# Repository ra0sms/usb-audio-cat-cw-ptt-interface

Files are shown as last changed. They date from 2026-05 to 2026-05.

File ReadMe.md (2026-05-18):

## USB AUDIO CAT PTT CW interface for any transceiver

One USB connection - two USB devices. 

USB Audio Codec and COM-port for CAT CW and PTT. Based on CH334R (usb-hub), CH340C (usb-com) and CM108B (usb audio).

More information - https://ra0sms.com/usb-audio-cat-interface/

-------------------------------------------

PCB dimension: 80*48 mm

[Gerber files](KiCad/usb_audio_cat/usb_audio_cat_gerbers.zip)

[Schematic](KiCad/usb_audio_cat/usb_audio_cat.pdf)

Recommended enclosure - 80-50-20 mm (https://aliexpress.ru/item/1005006828585850.html)

### PCB

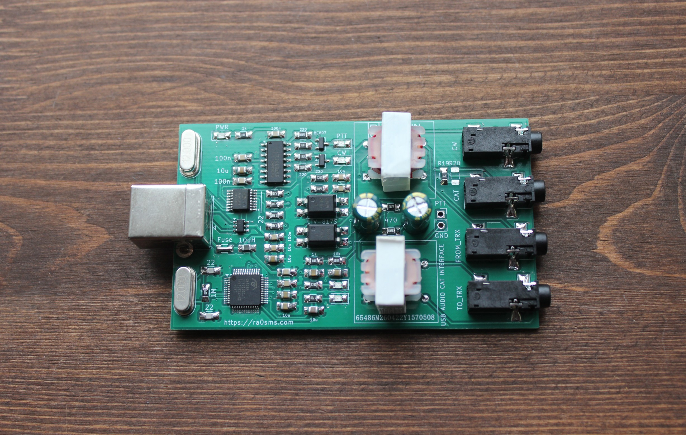
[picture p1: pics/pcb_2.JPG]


### Boxed version

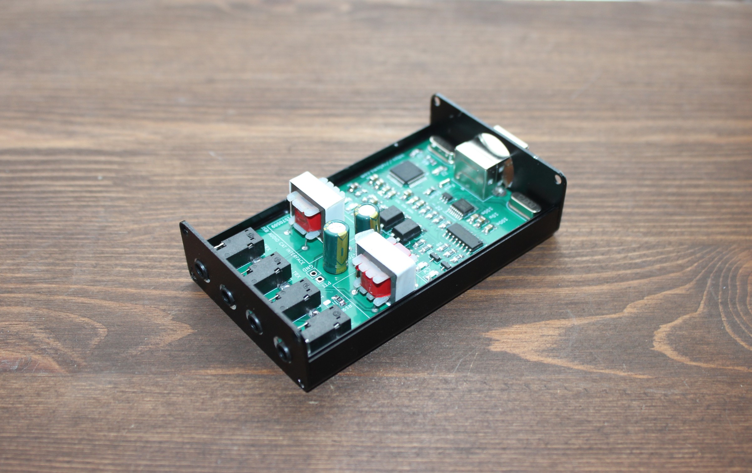
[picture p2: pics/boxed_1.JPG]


### Schematic

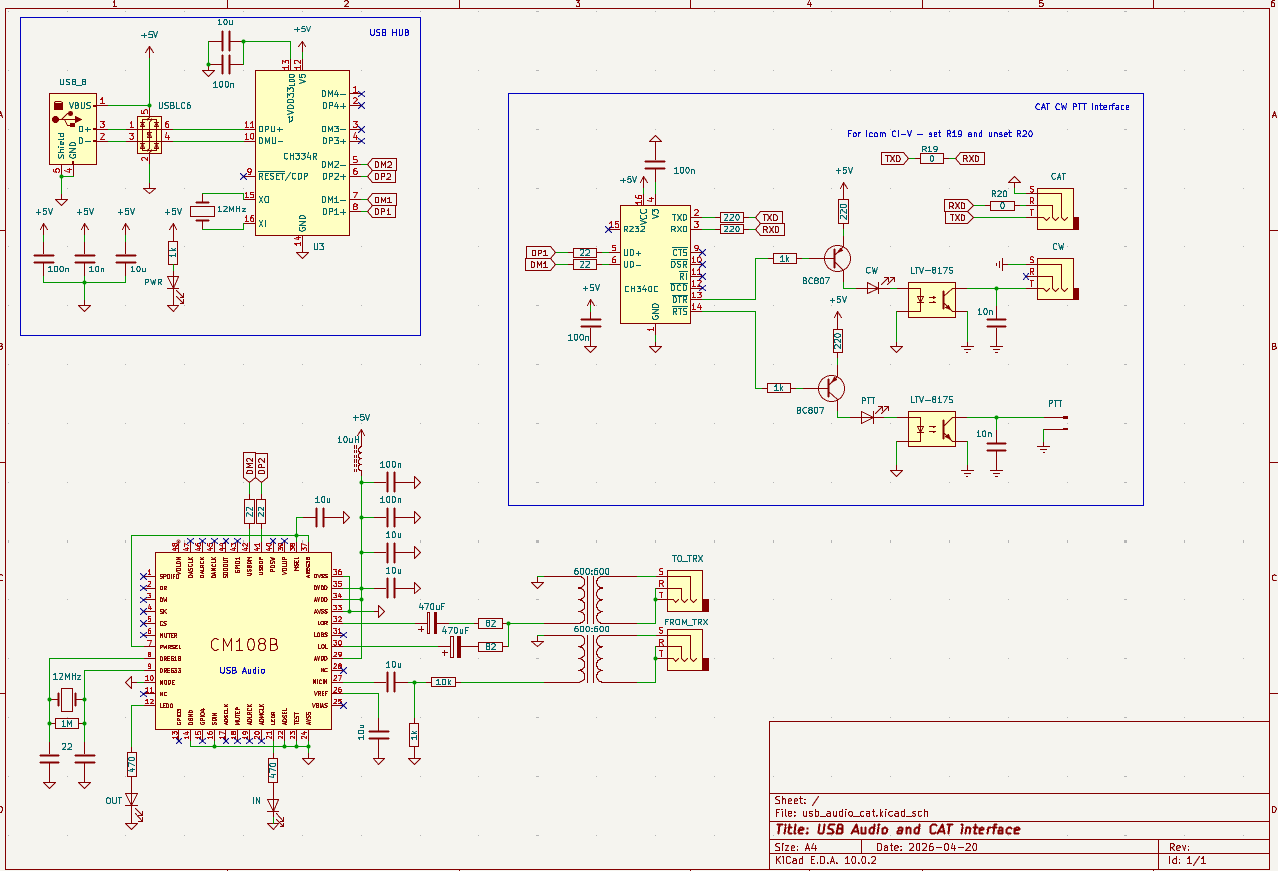
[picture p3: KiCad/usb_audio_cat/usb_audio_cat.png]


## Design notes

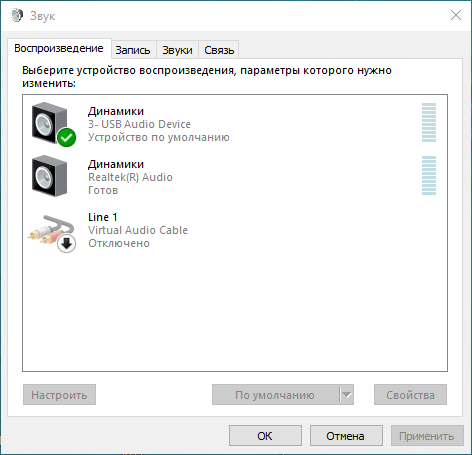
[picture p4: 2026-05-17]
pics/audio_windows_2.png

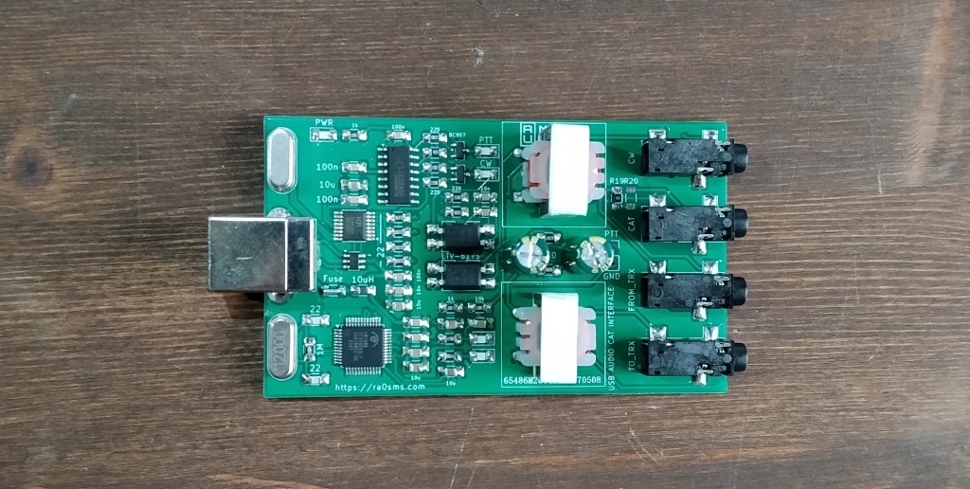
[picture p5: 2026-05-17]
pics/pcb_1.jpg

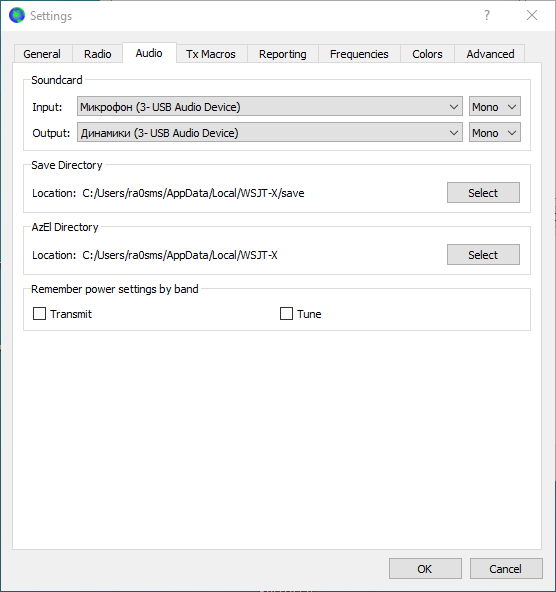
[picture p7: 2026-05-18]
pics/audio_wsjtx.png

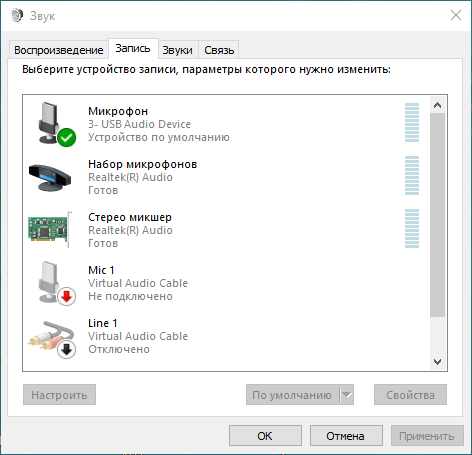
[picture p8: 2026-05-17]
pics/audio_windows_1.png

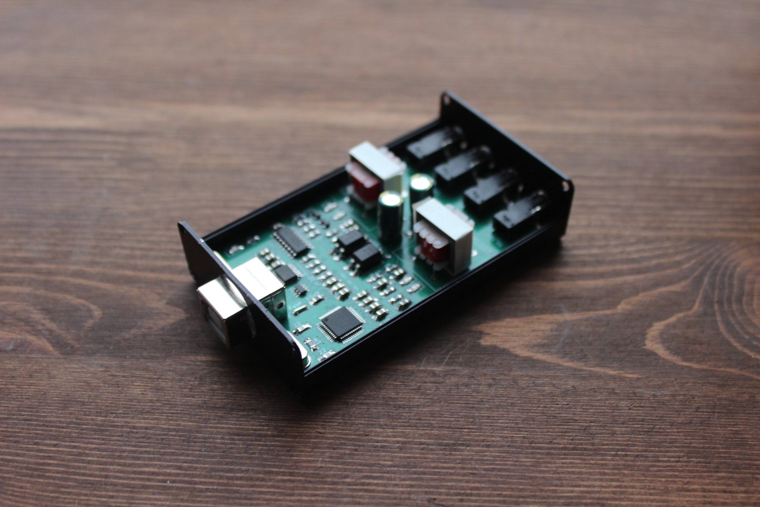
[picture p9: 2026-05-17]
pics/boxed_2.JPG

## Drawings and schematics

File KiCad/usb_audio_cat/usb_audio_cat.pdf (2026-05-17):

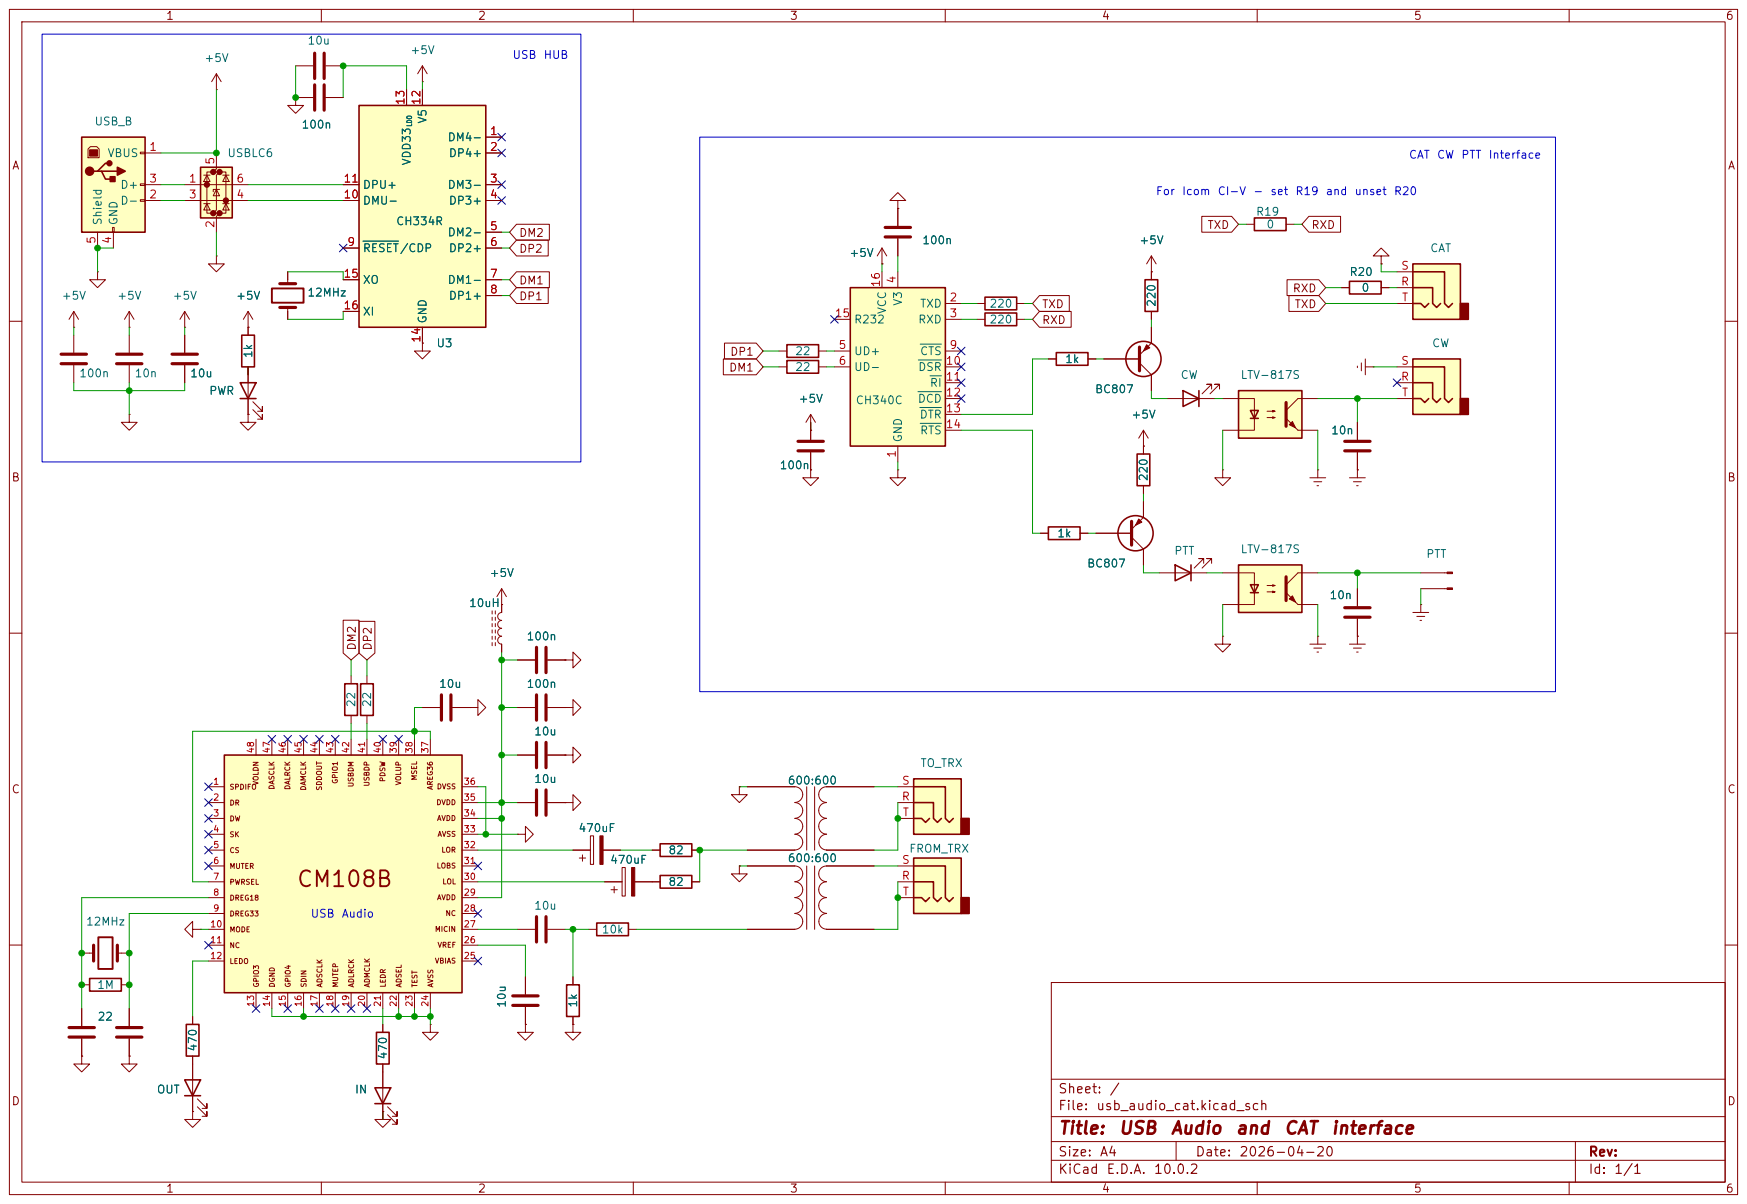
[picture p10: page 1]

For Icom CI-V - set R19 and unset R20 USB Audio

4 UD+ 5 UD- 6 CTS 9 DSR 10 RI 11 DCD 12 DTR 13 RTS 14 R232 15 VCC 16 CH340C

File: usb_audio_cat.kicad_sch
Title: USB Audio and CAT interface

Size: A4 | Rev:
KiCad E.D.A. 10.0.2 | Id: 1/1

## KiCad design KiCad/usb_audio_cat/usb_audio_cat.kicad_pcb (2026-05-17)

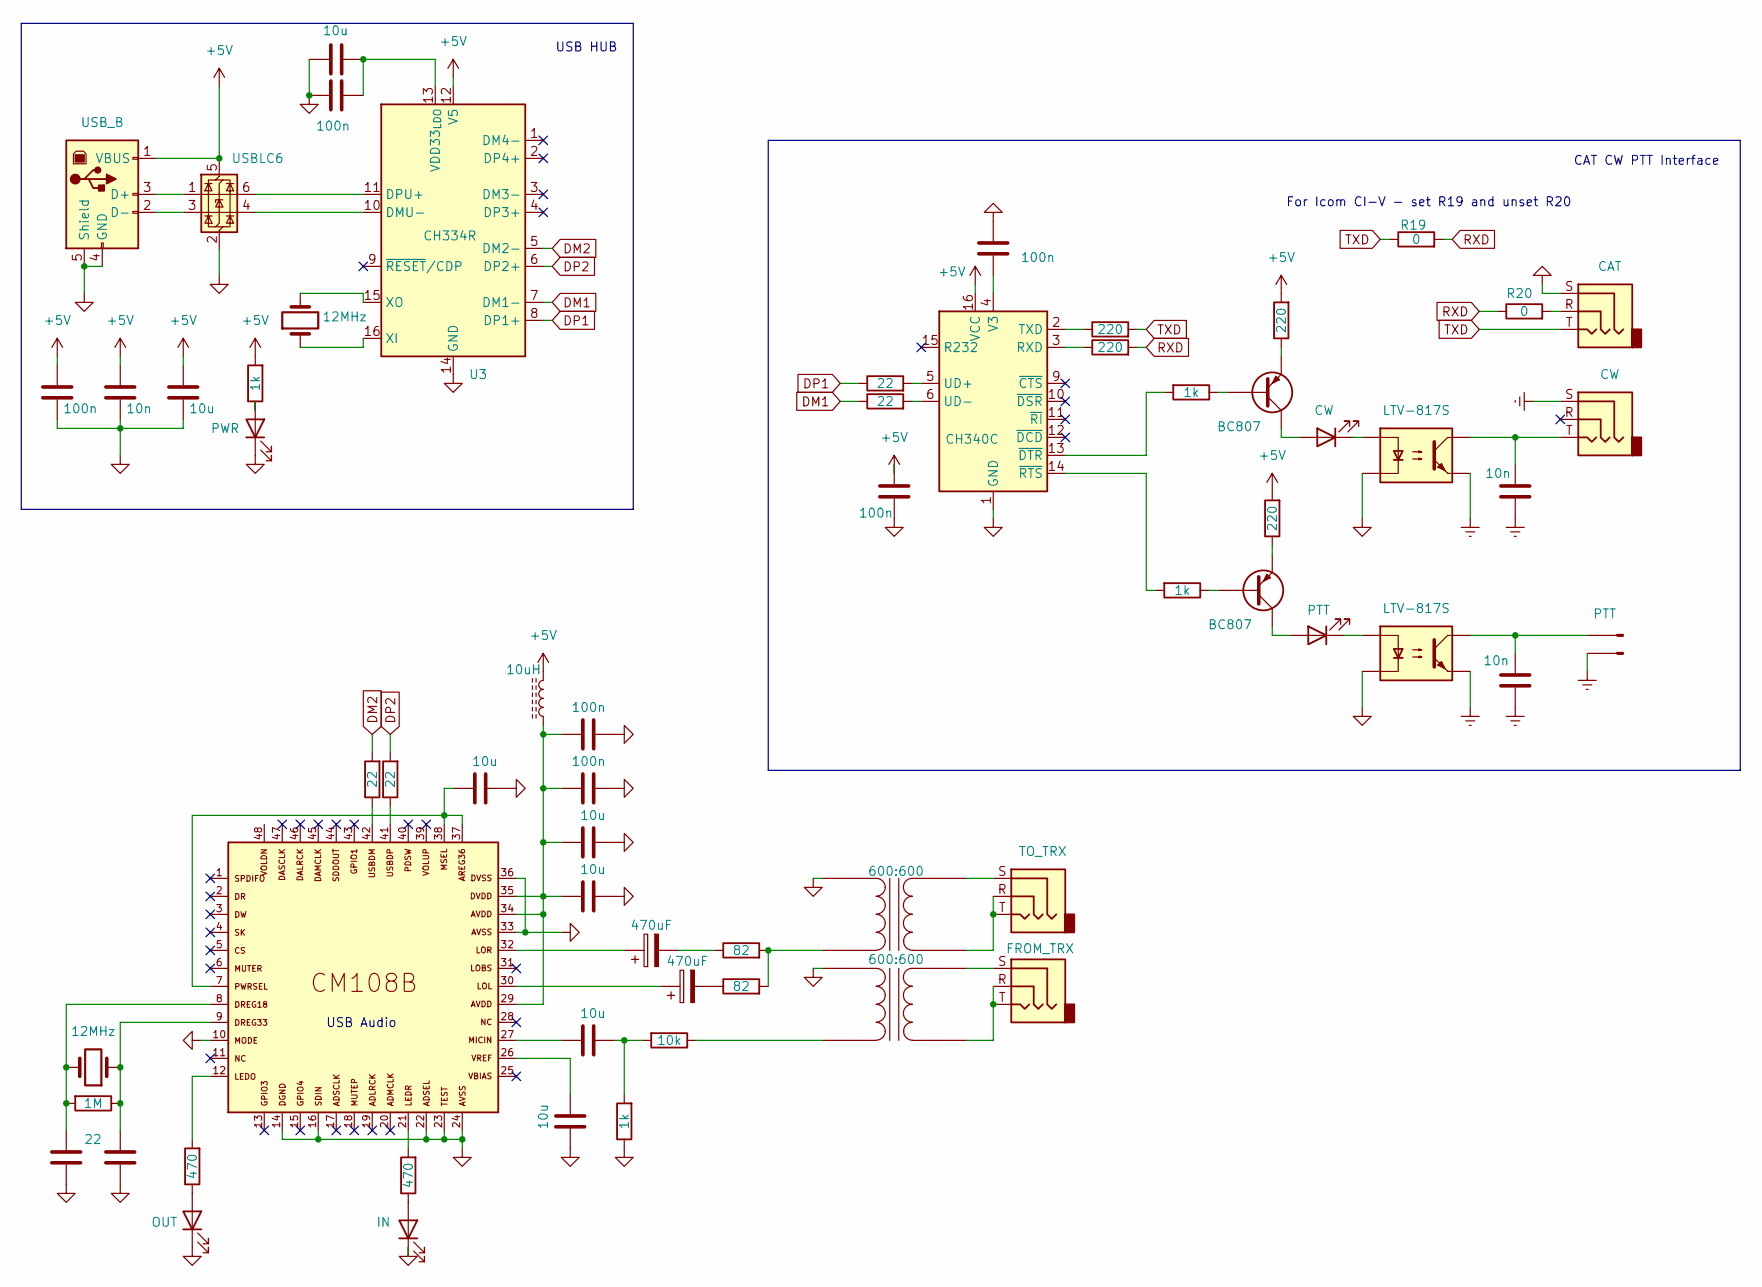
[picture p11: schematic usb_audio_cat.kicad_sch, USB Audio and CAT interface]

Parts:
C1, C3: 22; C_1206_3216Metric
C2, C7, C10, C11, C17, C18: 100n; C_1206_3216Metric
C4, C19, C20: 10n; C_1206_3216Metric
C5, C6, C8, C9, C12, C13, C14: 10u; C_1206_3216Metric
C15, C16: 470uF; CP_Radial_D5.0mm_P2.50mm
D1: PWR; LED_1206_3216Metric
D2: OUT; LED_1206_3216Metric
D3: IN; LED_1206_3216Metric
D4: PTT; LED_1206_3216Metric
D5: CW; LED_1206_3216Metric
J1: USB_B; USB_B_Lumberg_2411_02_Horizontal
J2: TO_TRX; Jack_3.5mm_CUI_SJ-3523-SMT_Horizontal
J3: FROM_TRX; Jack_3.5mm_CUI_SJ-3523-SMT_Horizontal
J4: CAT; Jack_3.5mm_CUI_SJ-3523-SMT_Horizontal
J5: CW; Jack_3.5mm_CUI_SJ-3523-SMT_Horizontal
J6: PTT; PinSocket_1x02_P2.54mm_Vertical
L1: 10uH; R_1206_3216Metric
Q1, Q2: BC807; SOT-23
R1, R7, R15, R16: 1k; R_1206_3216Metric
R2: 1M; R_1206_3216Metric
R3, R6: 470; R_1206_3216Metric
R4, R5, R11, R12: 22; R_1206_3216Metric
R8: 10k; R_1206_3216Metric
R9, R10: 82; R_1206_3216Metric
R13, R14, R17, R18: 220; R_1206_3216Metric
R19, R20: 0; R_1206_3216Metric
T1, T2: 600:600; Transformer_NF_ETAL_1-1_P1200
U1: USBLC6; SOT-23-6
U2: CM108B; LQFP-48_7x7mm_P0.5mm
U3: CH334R; QSOP-16_3.9x4.9mm_P0.635mm
U4: CH340C; SOIC-16_3.9x9.9mm_P1.27mm
U5, U6: LTV-817S; SMDIP-4_W9.53mm
Y1, Y2: 12MHz; Crystal_HC18-U_Vertical

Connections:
+5V: C2.1, C4.1, C5.1, C17.1, J1.1 (VBUS), L1.2, R1.2, R17.2, R18.2, U1.5 (VBUS), U3.12 (V5), U4.16 (VCC)
DM1: R12.1, U3.7 (DM1-)
DM2: R4.2, U3.5 (DM2-)
DP1: R11.1, U3.8 (DP1+)
DP2: R5.2, U3.6 (DP2+)
GND: C1.1, C2.2, C3.1, C4.2, C5.2, C6.1, C7.1, C8.2, C9.1, C10.2, C11.2, C12.2, C13.2, C17.2, C18.1, D1.1 (K), D2.1 (K), D3.1 (K), J1.4 (GND), J1.5 (Shield), J4.S, R7.1, T1.1 (AA), T2.1 (AA), U1.2 (GND), U2.10, U2.14, U2.16, U2.22, U2.23, U2.24, U2.33, U2.36, U3.14 (GND), U4.1 (GND), U5.2, U6.2
GNDREF: C19.2, C20.2, J5.S, J6.2, U5.3, U6.3
unnamed: C1.2, R2.2, U2.8, Y1.2
unnamed: C3.2, R2.1, U2.9, Y1.1
unnamed: C8.1, U2.7, U2.37, U2.38
unnamed: C9.2, U2.26
unnamed: C10.1, C11.1, C12.1, C13.1, L1.1, U2.29, U2.34, U2.35
unnamed: C14.1, U2.27
unnamed: C14.2, R7.2, R8.2
unnamed: C15.1, U2.32
unnamed: C15.2, R9.1
unnamed: C16.1, U2.30
unnamed: C16.2, R10.1
unnamed: C19.1, J5.T, U5.4
unnamed: D1.2 (A), R1.1
unnamed: D2.2 (A), R3.1
unnamed: D3.2 (A), R6.1
unnamed: D4.2 (A), Q1.3 (C)
unnamed: D4.1 (K), U6.1
unnamed: D5.2 (A), Q2.3 (C)
unnamed: D5.1 (K), U5.1
unnamed: J1.3 (D+), U1.1 (I/O1)
unnamed: J1.2 (D-), U1.3 (I/O2)
unnamed: J4.R, R20.2
unnamed: C20.1, J6.1, U6.4
unnamed: Q1.1 (B), R15.1
unnamed: Q1.2 (E), R17.1
unnamed: Q2.1 (B), R16.1
unnamed: Q2.2 (E), R18.1
unnamed: R3.2, U2.12
unnamed: R4.1, U2.42
unnamed: R5.1, U2.41
unnamed: R6.2, U2.21
unnamed: R9.2, R10.2, T1.3 (AB)
unnamed: J2.R, J2.T, T1.4 (SA)
unnamed: J2.S, T1.6 (SB)
unnamed: R8.1, T2.3 (AB)
unnamed: J3.R, J3.T, T2.4 (SA)
unnamed: J3.S, T2.6 (SB)
unnamed: U1.4 (I/O2), U3.10 (DMU-)
unnamed: U1.6 (I/O1), U3.11 (DPU+)
unnamed: C6.2, C7.2, U3.13 (VDD33_{LDO})
unnamed: U3.16 (XI), Y2.1
unnamed: U3.15 (XO), Y2.2
unnamed: R14.1, U4.3 (RXD)
unnamed: R13.1, U4.2 (TXD)
unnamed: R11.2, U4.5 (UD+)
unnamed: R12.2, U4.6 (UD-)
unnamed: C18.2, U4.4 (V3)
unnamed: R16.2, U4.13 (~DTR)
unnamed: R15.2, U4.14 (~RTS)
RXD: R14.2, R19.2, R20.1
TXD: J4.T, R13.2, R19.1

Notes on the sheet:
For Icom CI-V - set R19 and unset R20
USB Audio
CAT CW PTT Interface
USB HUB

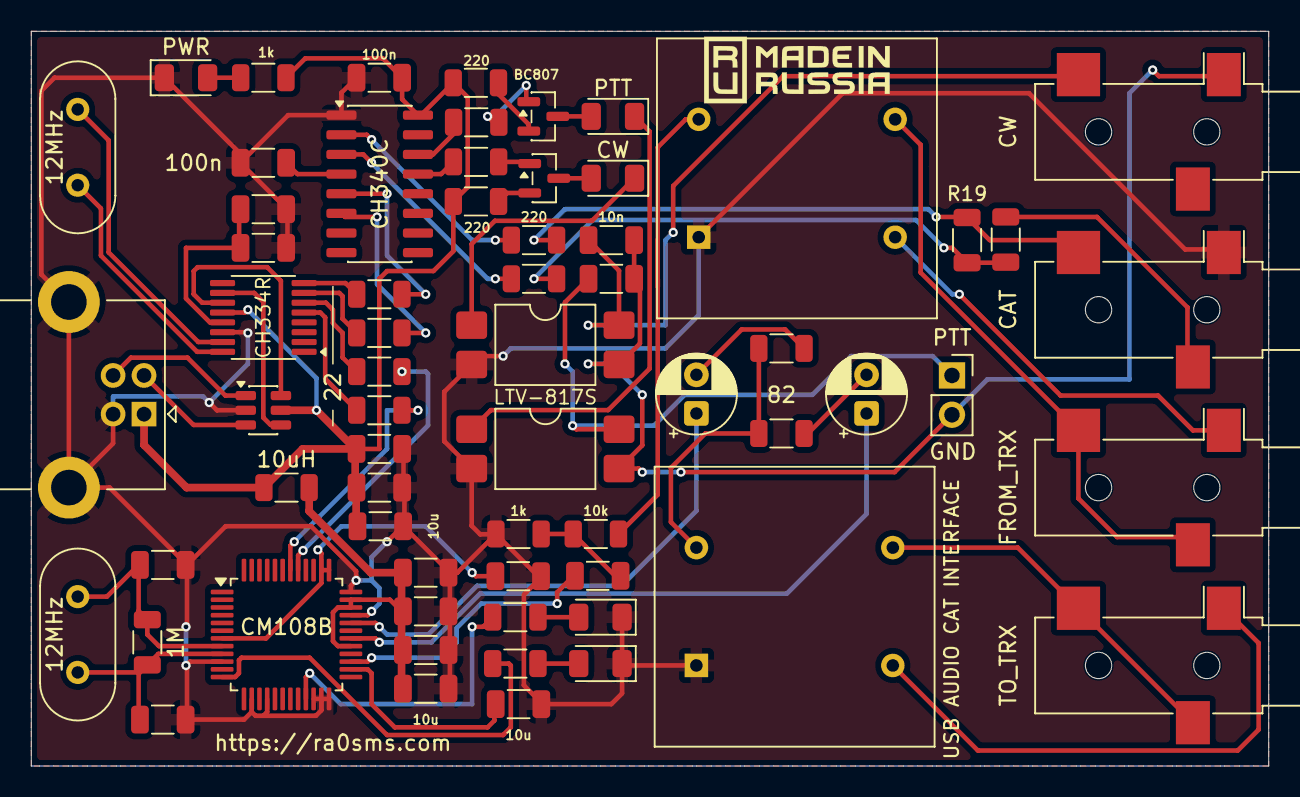
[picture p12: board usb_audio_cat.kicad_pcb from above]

Board: 2 copper layers, 80.0 x 47.5 mm, 64 parts (0 on the bottom side), 58 nets.
